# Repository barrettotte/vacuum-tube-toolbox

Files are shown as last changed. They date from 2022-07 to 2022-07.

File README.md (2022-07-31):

# vacuum-tube-toolbox

A work in progress OpenSCAD library (and eventually KiCad designs) to make tinkering with vacuum tubes quicker/easier.

## Current Features

- Tube holders (single/multiple)
- Plugin coils for building old radio coil tubes

## Images

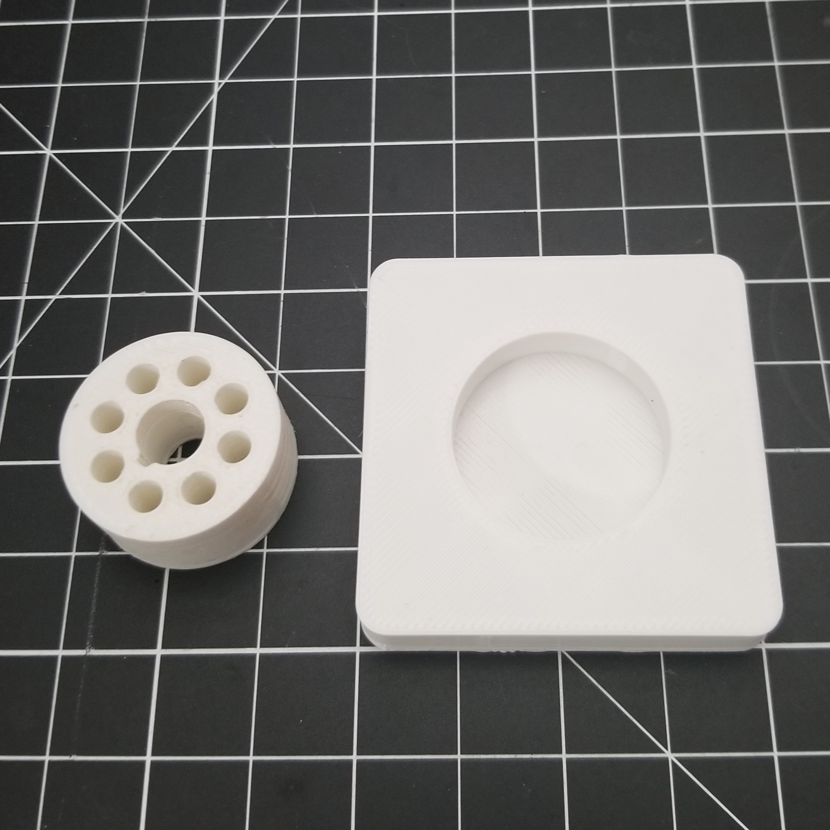
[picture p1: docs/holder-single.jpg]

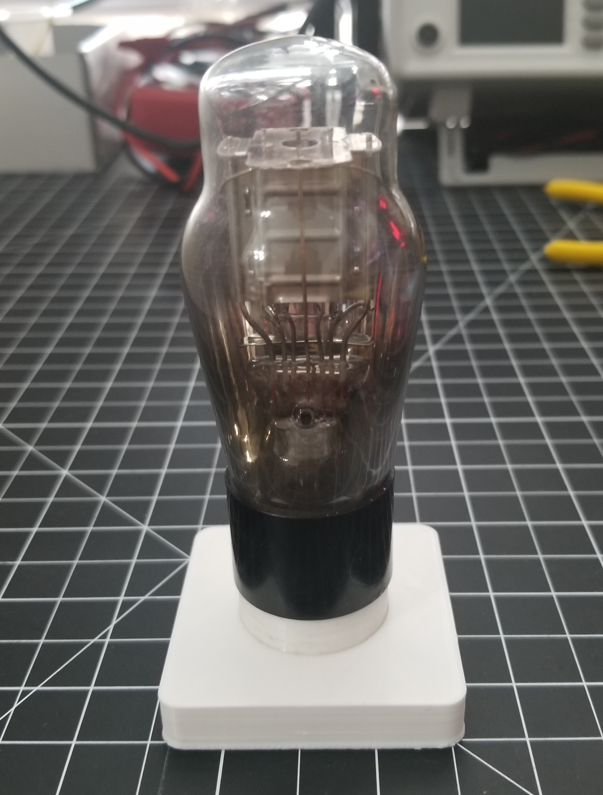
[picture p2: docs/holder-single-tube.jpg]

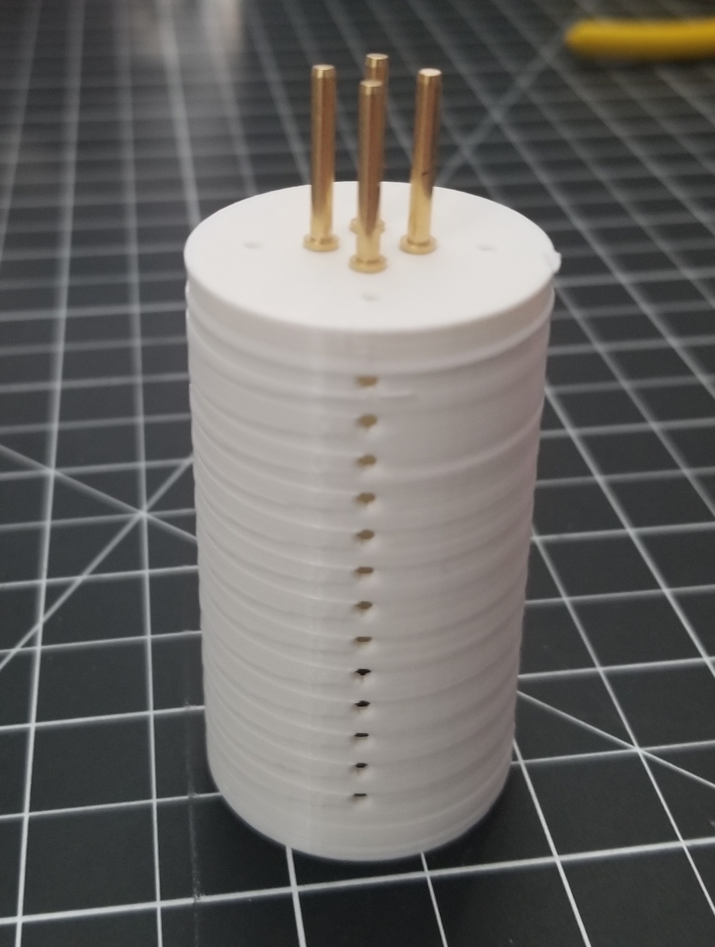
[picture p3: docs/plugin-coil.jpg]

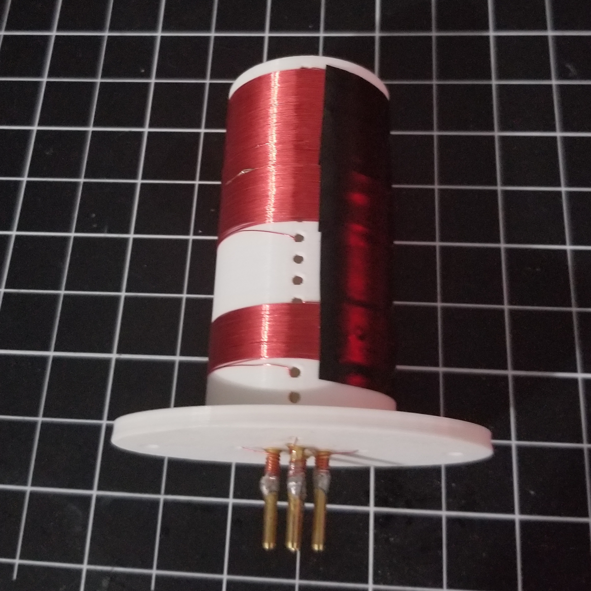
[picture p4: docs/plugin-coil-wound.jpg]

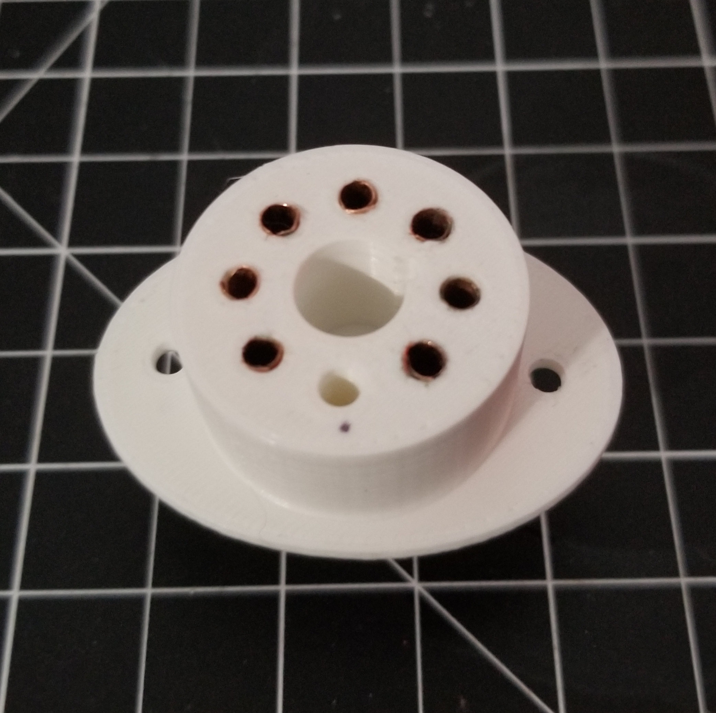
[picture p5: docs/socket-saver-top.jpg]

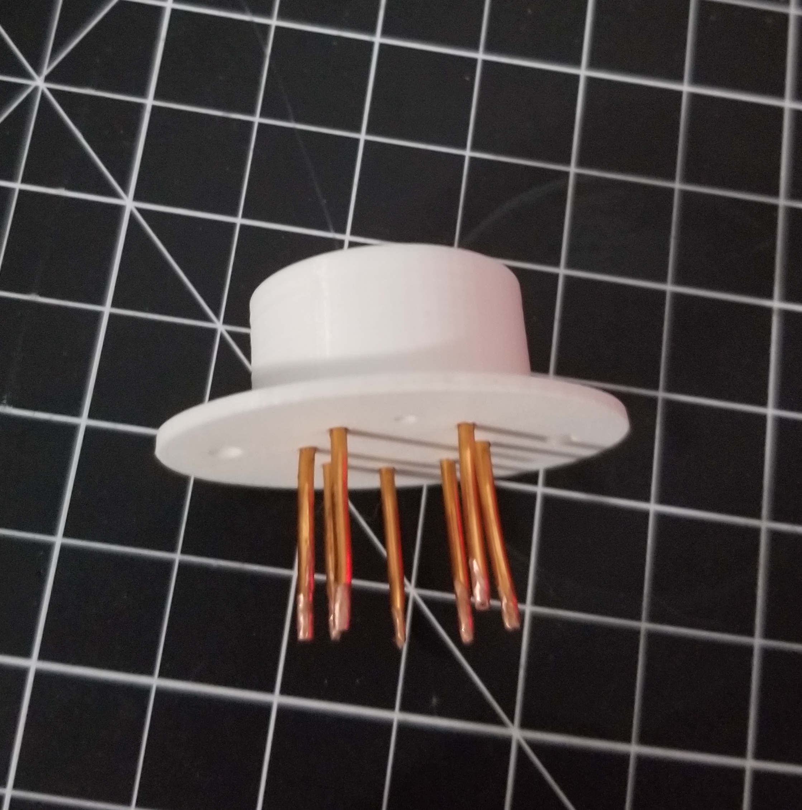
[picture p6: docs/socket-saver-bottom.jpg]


## Hardware

For 3D prints with holes/slots I generally use a 0.1mm tolerance 
to account for errors and/or print bed deformation.

### Pins

Vacuum tube pins can be found by searching for "swage mount pins".
This honestly took me forever to find the right google search.

I sourced from:
- https://www.digikey.com/en/products/detail/mill-max-manufacturing-corp/3104-2-00-15-00-00-08-0/436491
- https://www.digikey.com/en/products/detail/mill-max-manufacturing-corp/4395-0-00-15-00-00-08-0/10063634
- https://www.digikey.com/en/products/detail/mill-max-manufacturing-corp/6331-0-00-15-00-00-08-0/10063644
- https://www.mill-max.com/products/new/swage-mount-pcb-pins-for-interconnect-applications
- https://www.mill-max.com/search/tags/swage_mount?src=19

I think that pins can be made by hand by working hollow 2-3mm brass tubing.
This would probably be cheaper and more convenient, but I have not pursued this seriously yet.

For installing pins, print base with pin diameters around 0.05 mm smaller.
Then, heat up pin with soldering iron and melt the pin into the base.

## Building a Socket Saver

- Print mounted tube socket with pin diameter of 3mm and mount pin diameter of 2mm.
- Prepare pin components.
  - **pin** - 21mm segment of 1.5mm diameter magnet wire.
  - **pin socket** - 10mm x 16mm copper foil cut out.
- Sand ~5mm on both ends of magnet wire pin.
- Wrap copper foil segment around pin. Then, Solder foil to pin, making sure not to add extra diameter.
- Use multimeter to check continuity of each pin
- Insert completed pin with pin socket into tube socket.
  - If loose, consider super gluing or increasing diameter of pin socket.
- Slightly insert vacuum tube and recheck continuity between tube pins and socket pins.

## Future Features

Hoping to get to these items as other projects require them.

- Breakout boards for common tube types (KiCad)
- Breadboard adapters for common tube types (KiCad)
- attempt all basic socket types listed in - https://en.wikipedia.org/wiki/Tube_socket#Summary_of_base_details

## Development Dependencies

- OpenSCAD 2021.01+ - `apt-get -y install openscad`

## References

- https://en.wikipedia.org/wiki/Tube_socket

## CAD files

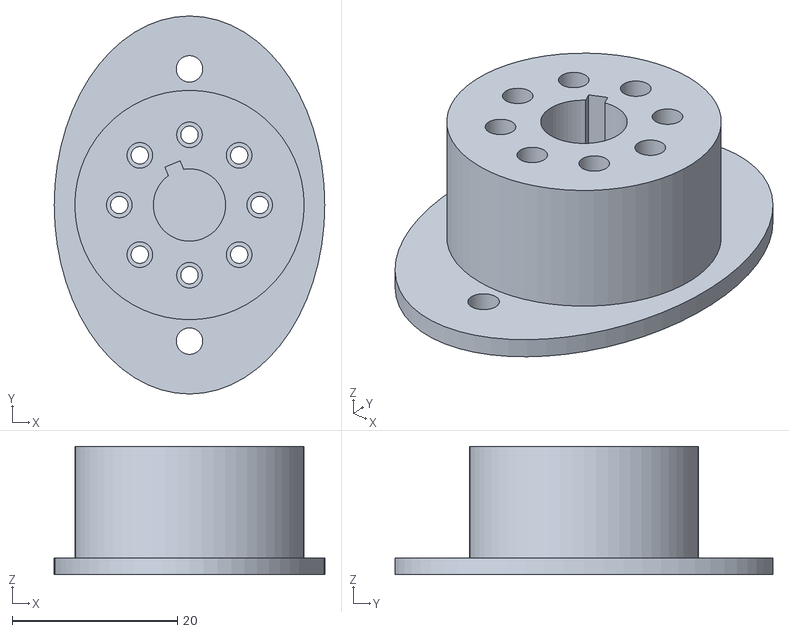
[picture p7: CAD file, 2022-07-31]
examples/socket_8_mounted.stl
32.8 x 45.8 x 15.5

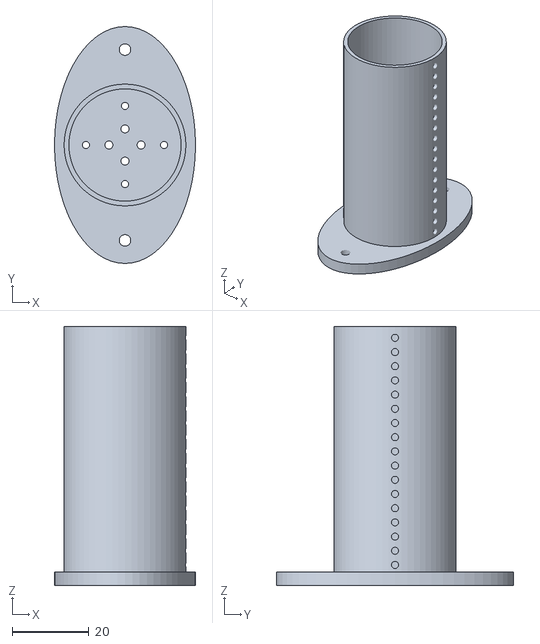
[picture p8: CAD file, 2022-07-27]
examples/plugin_coil.stl
36.8 x 61.8 x 67.5

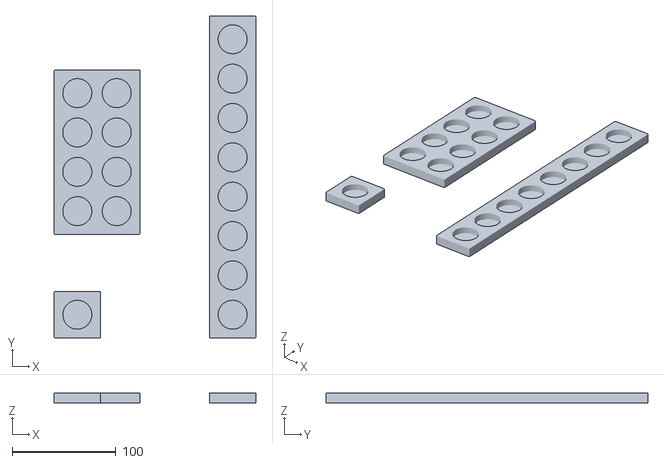
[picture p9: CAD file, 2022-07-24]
examples/demo_holders.stl
195.0 x 311.0 x 10.0

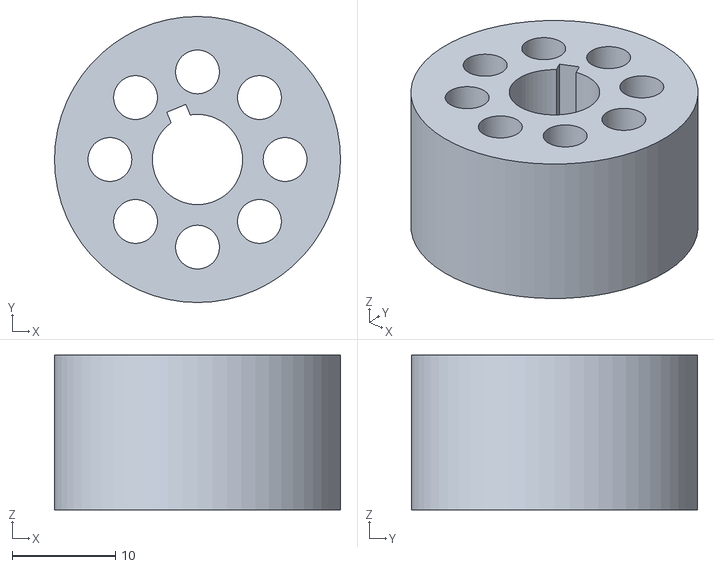
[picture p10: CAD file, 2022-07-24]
examples/socket_8.stl
27.8 x 27.8 x 15.0

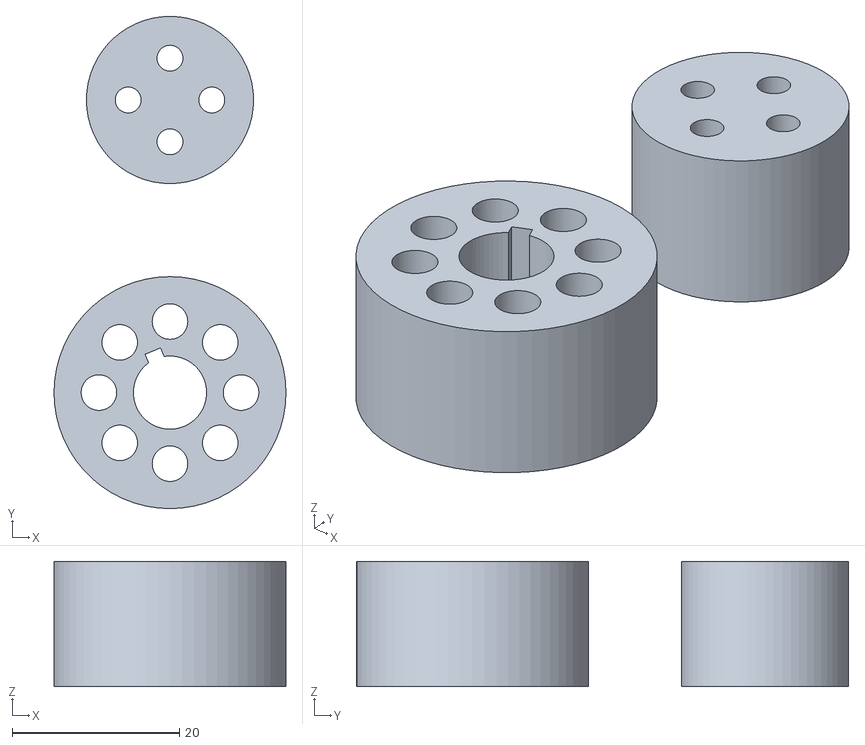
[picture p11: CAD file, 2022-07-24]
examples/demo_sockets.stl
27.8 x 58.9 x 15.0

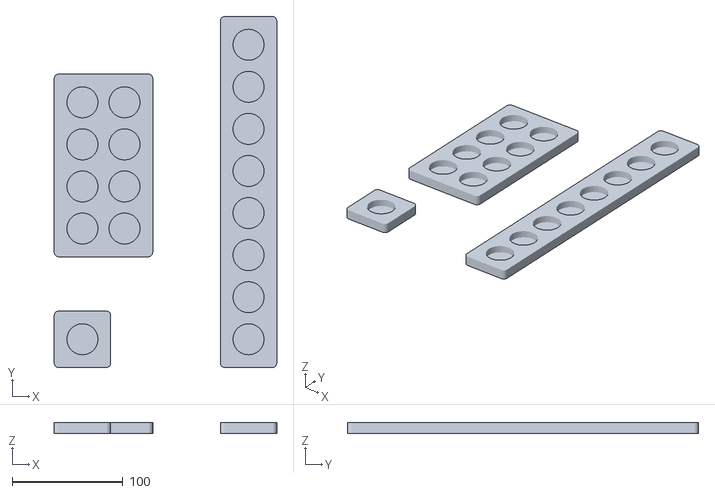
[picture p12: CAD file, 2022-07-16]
examples/holder_multiple.stl
201.0 x 317.0 x 10.0

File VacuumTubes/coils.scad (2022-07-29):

// Plugin coils for building old radio coil tubes

// Base plugin coil
module plugin_coil(
    height,            // height of tube coil
    wall_thickness,    // thickness of tube
    bottom_thickness,  // thickness between bottom and inside of tube
    pins,              // number of pins
    core_diameter,     // diameter of tube
    pin_diameter,      // diameter of each pin
    wire_hole_diameter // diameter of wire to pass through tube
) {
    core_radius = core_diameter/2;

    difference() {
        // core
        cylinder(d=core_diameter, h=height-wall_thickness);

        // cut out center
        translate([0,0,bottom_thickness])
            cylinder(d=core_diameter-wall_thickness, h=height);
        
        // cut out pin holes
        for (i = [0:pins-1]) {
            pin_x = sin(360 * i / pins) * (pin_diameter * 2);
            pin_y = cos(360 * i / pins) * (pin_diameter * 2);
            translate([pin_x, pin_y, 0])
                cylinder(d=pin_diameter, h=bottom_thickness);
        }

        // cut out side wire holes
        hole_height_max = height - bottom_thickness - wire_hole_diameter;
        for (z = [(bottom_thickness + wire_hole_diameter) : (wire_hole_diameter * 2) : hole_height_max]) {
            translate([(core_radius - wall_thickness), 0, z])
                rotate([0,90,0])
                    cylinder(d=wire_hole_diameter, h=wall_thickness);
        }

        // cut out bottom wire holes
        for (i = [0:pins-1]) {
            pin_x = sin(360 * i / pins) * (wire_hole_diameter * 5.5);
            pin_y = cos(360 * i / pins) * (wire_hole_diameter * 5.5);
            translate([pin_x, pin_y, 0])
                cylinder(d=wire_hole_diameter, h=bottom_thickness);
        }
    }
}

// plugin coil with screw mounts
module plugin_coil_mounted(
    height,              //
    wall_thickness,      //
    bottom_thickness,    //
    pins,                //
    core_diameter,       //
    pin_diameter,        //
    wire_hole_diameter,  //
    mount_hole_diameter, // diameter of mounting holes 
    mount_width          // width of mounting base on each side
) {
    union() {
        // base tube
        plugin_coil(height, wall_thickness, bottom_thickness, pins, core_diameter, pin_diameter, wire_hole_diameter);

        // mount
        difference() {
            linear_extrude(height=bottom_thickness)
                resize([core_diameter+5, (2 * mount_width) + core_diameter])
                    circle(d=1);
            cylinder(d=core_diameter, h=bottom_thickness);

            // holes
            hole_y = (core_diameter/2) + mount_width - (2 * mount_hole_diameter);

            translate([0, hole_y, 0])
                cylinder(d=mount_hole_diameter, h=bottom_thickness);
            translate([0, -hole_y, 0])
                cylinder(d=mount_hole_diameter, h=bottom_thickness);
        }
    }
}

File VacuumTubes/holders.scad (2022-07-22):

// Organization for displaying vacuum tubes.

// Base tube holder
module tube_holder(
    rows,            // rows of holder
    cols,            // columns of holder
    socket_diameter, // diameter of socket cutout
    socket_padding,  // padding around socket
    socket_depth,    // how far down the socket should cut into the holder
    height,          // height of holder
    edge_padding,    // extra padding from edge of holder to last socket slot
    fillet           // fillet around holder
) {
    socket_slot = socket_diameter + (socket_padding * 2);
    slot_offset = edge_padding + (socket_slot / 2);

    difference() {
        // create base
        hull() {
            base_x = (rows * socket_slot) + (2 * edge_padding);
            base_y = (cols * socket_slot) + (2 * edge_padding);

            translate([0, 0, 0]) cylinder(r=fillet, h=height);
            translate([base_x, 0, 0]) cylinder(r=fillet, h=height);
            translate([0, base_y, 0]) cylinder(r=fillet, h=height);
            translate([base_x, base_y, 0]) cylinder(r=fillet, h=height);
        }

        // socket holes
        for (i = [0:rows-1]) {
            for (j = [0:cols-1]) {
                socket_x = slot_offset + (i * socket_slot);
                socket_y = slot_offset + (j * socket_slot);

                translate([socket_x, socket_y, height-socket_depth])
                    cylinder(d=socket_diameter, h=socket_depth);
            }
        }
    }
}

// Square tube holder
module holder_square(length, socket_diameter, socket_padding, socket_depth, height, edge_padding, fillet) {
    tube_holder(length, length, socket_diameter, socket_padding, socket_depth, height, edge_padding, fillet);
}

// Single tube holder
module holder_single(socket_diameter, socket_padding, socket_depth, height, edge_padding, fillet) {
    holder_square(1, socket_diameter, socket_padding, socket_depth, height, edge_padding, fillet);
}

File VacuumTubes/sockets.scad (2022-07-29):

// Sockets for various vacuum tubes

// Base tube socket
module tube_socket(
    pins,              // number of pins
    pin_diameter,      // diameter of each pin
    pin_offset,        // pin offset from center
    socket_diameter,   // diameter of socket base
    socket_height,     // height of socket base

    center_diameter=0, // diameter of center hole in socket base
    notch_length=0     // length of center notch
) {
    socket_radius = socket_diameter / 2; // radius of socket base
    pin_radius = pin_diameter / 2;       // radius of each pin

    difference() {
        // socket base
        cylinder(socket_height, socket_radius, socket_radius);

        // pin holes
        for (i = [0:pins-1]) {
            translate([sin(360*i/pins) * pin_offset, cos(360*i/pins) * pin_offset, 0])
                cylinder(socket_height*2, pin_radius, pin_radius);
        }

        // center hole
        if (center_diameter > 0) {
            center_radius = center_diameter / 2; // radius of center hole
            notch_rotation = 90 + (180 / pins);  // notch rotation position

            union() {
                if (notch_length > 0) {
                    rotate([0, 0, notch_rotation])
                        translate([center_radius, 0, 0])
                            cube(size=[notch_length, notch_length, socket_height*2], center=true);
                }
                // hole
                cylinder(socket_height*2, center_radius, center_radius);
            }
        }
    }
}

// socket with screw mounts
module socket_mounted(
    pins, pin_diameter, pin_offset, socket_diameter, socket_height,

    center_diameter=0, notch_length=0,
    mount_pin_diameter,   // diameter of pin at bottom (mount)
    mount_hole_diameter,  // diameter of mounting holes 
    mount_width,          // width of mounting base on each side
    mount_height          // height of base mount
) {
    difference() {
        union() {
            // base socket
            tube_socket(pins, pin_diameter, pin_offset, socket_diameter,
                socket_height, center_diameter, notch_length);

            // mount
            difference() {
                linear_extrude(height=2)
                    resize([socket_diameter+5, (2 * mount_width) + socket_diameter])
                        circle(d=1);

                // holes
                hole_y = (socket_diameter/2) + mount_width - (2 * mount_hole_diameter);

                translate([0, hole_y, 0])
                    cylinder(d=mount_hole_diameter, h=mount_height);
                translate([0, -hole_y, 0])
                    cylinder(d=mount_hole_diameter, h=mount_height);
            }
        }
        // bottom pin holes - leave room to melt through
        for (i = [0:pins-1]) {
            translate([sin(360*i/pins) * pin_offset, cos(360*i/pins) * pin_offset, 0])
                cylinder(d=mount_pin_diameter, h=mount_height);
        }
    }
}

// 8 pin socket
module socket_8(
    pin_diameter, pin_offset, socket_diameter, socket_height, 
    center_diameter=0, notch_length=0
) {
    tube_socket(8, pin_diameter, pin_offset, socket_diameter, socket_height, center_diameter, notch_length);
}

// 4 pin socket
module socket_4(
    pin_diameter, pin_offset, socket_diameter, socket_height, 
    center_diameter=0, notch_length=0
) {
    tube_socket(4, pin_diameter, pin_offset, socket_diameter, socket_height, center_diameter, notch_length);
}

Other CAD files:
examples/octal_socket.stl
examples/holders.stl
examples/socket_octal.stl
examples/demo_holders.scad
examples/demo_sockets.scad
examples/holder_multiple.scad
examples/holders.scad
examples/octal_socket.scad
examples/plugin_coil.scad
examples/single_tube_holder.scad
examples/socket_8.scad
examples/socket_8_mounted.scad

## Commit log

2022-06-05 base tube holder and octal socket
    [holders.scad, lib.scad, multiple_holders.scad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]
2022-06-17 add makefile for examples
    [holder_multiple.scad, holder_multiple.stl, holder_single.scad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]
2022-06-18 plugin coil
    [coil_plugin.scad, coil_plugin.stl]
2022-06-18 plugin coils
    [coils.scad]
2022-06-18 fix plugin coil
    [coil_plugin.stl, coils.scad]
2022-07-16 add wire holes to bottom of plugin coil
    [coil_plugin.stl, coils.scad, holder_multiple.stl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]
2022-07-17 plugin coil with n pins
    [coil_plugin.stl, coils.scad]
2022-07-17 add bottom thickness to plugin coil
    [coil_plugin.stl, coils.scad]
2022-07-22 clean up library
    [coil_plugin.scad, coil_plugin.stl, coils.scad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]
2022-07-23 update coil
    [coil_plugin.scad]
2022-07-23 fix coil plugin example
    [coil_plugin.scad, coil_plugin.stl]
2022-07-23 remove pin tolerance from plugin coil
    [coil_plugin.scad, coil_plugin.stl]
2022-07-23 add screw mounts to plugin coil
    [coil_plugin.scad, coil_plugin.stl, coils.scad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]
2022-07-23 add demo sockets and socket optional params
    [demo_holders.scad, demo_holders.stl, demo_sockets.scad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]
2022-07-24 rename socket modules
    [demo_holders.stl, demo_sockets.scad, demo_sockets.stl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]
2022-07-24 add mountable socket
    [coils.scad, demo_holders.scad, demo_sockets.scad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]
2022-07-27 tweak examples and mounted socket
    [coils.scad, plugin_coil.scad, plugin_coil.stl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]
2022-07-29 tweak mounted octal socket example
    [socket_8_mounted.scad, socket_8_mounted.stl]
2022-07-31 socket saver done
    [socket_8_mounted.scad, socket_8_mounted.stl]
2022-07-31 add images of socket saver and wound plugin coil
